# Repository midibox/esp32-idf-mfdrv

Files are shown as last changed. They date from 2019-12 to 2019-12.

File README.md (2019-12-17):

# MBHP_MF_NG for ESP32

## Introduction

This application is originated from the PIC based MBHP_MF_NG project: http://www.ucapps.de/mbhp_mf_ng.html

Currently used as a "Proof of Concept" for ESP32 based motorfader control.

Advantage: due to the dedicated PWM outputs of ESP32 we get much more accurate control over the motors.

More documentation to follow...

## Important

Please optimize the app configuration with "idf.py menuconfig":

* Compiler Options->Optimization Level: set to -Os (Release)
* Component Config->ESP32 Specific: set Minimum Supported ESP32 Revision to 1 (if you have a newer device...)
* Component Config->ESP32 Specific: set CPU frequency to 240 MHz
* Component Config->Log output: set to Warning (or use Info if you want to follow the data flow - but it will decrease performance!)

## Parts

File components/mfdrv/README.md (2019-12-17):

# Motorfader Driver

## Introduction

This driver is originated from:

* the assembly based MBHP_MF_NG project: http://www.ucapps.de/mbhp_mf_ng.html
* C based MIOS32 variant (which is an older implementation): https://github.com/midibox/mios32/blob/master/mios32/common/mios32_mf.c

Currently used as a "Proof of Concept" for ESP32 based motorfader control.

Advantage: due to the dedicated PWM outputs of ESP32 we get much more accurate control over the motors.

More documentation to follow...

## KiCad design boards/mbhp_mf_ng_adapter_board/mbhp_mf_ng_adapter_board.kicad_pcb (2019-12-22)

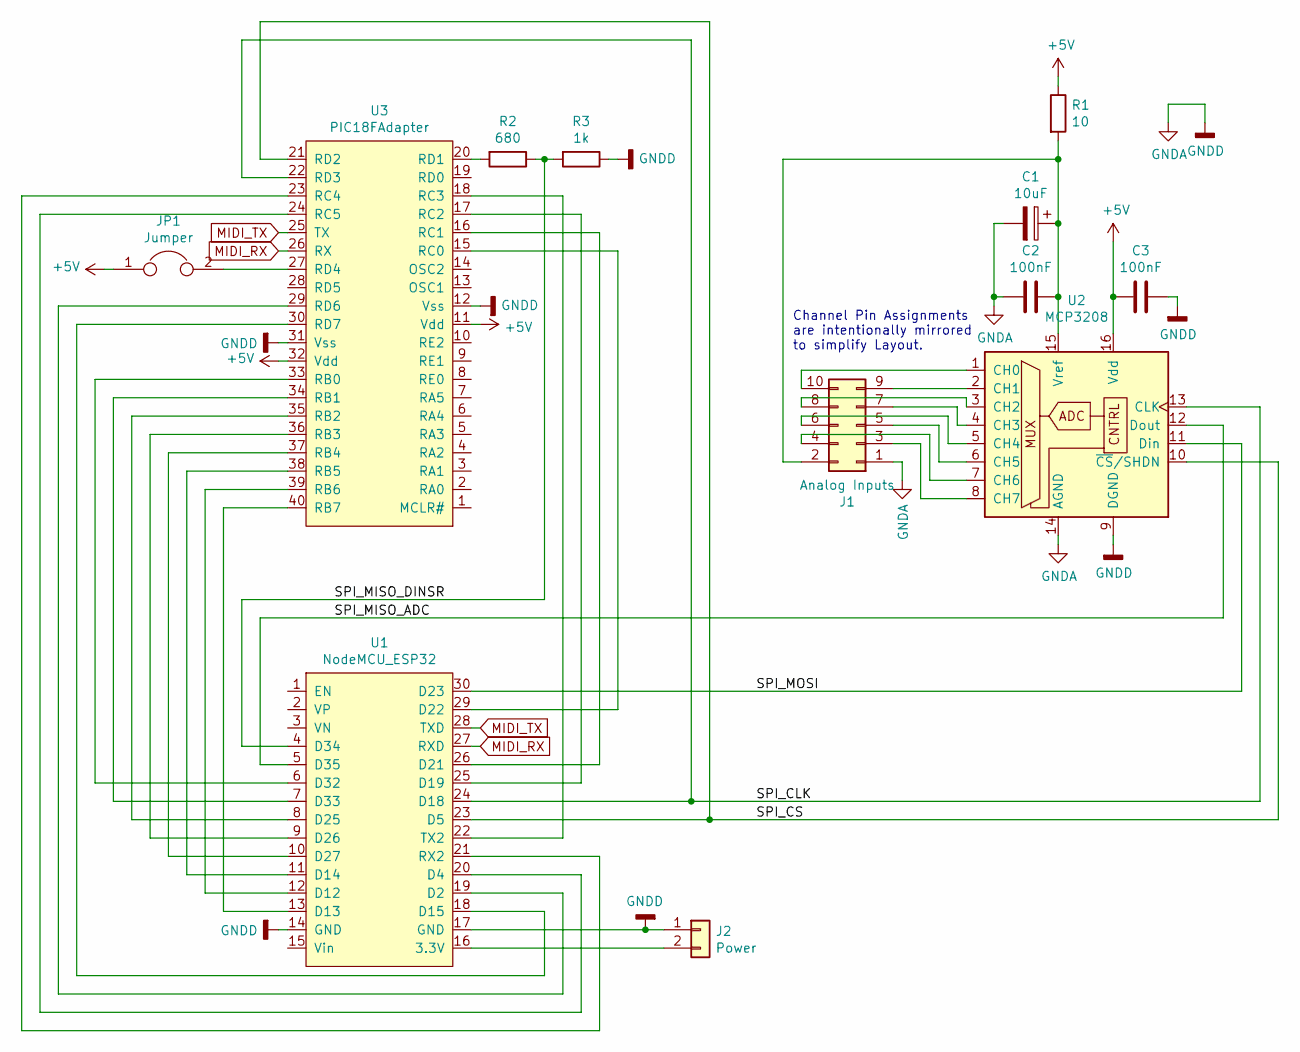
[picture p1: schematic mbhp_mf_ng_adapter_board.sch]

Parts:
C1: 10uF; CP_Radial_D5.0mm_P2.50mm
C2, C3: 100nF; C_Rect_L4.6mm_W2.0mm_P2.50mm_MKS02_FKP02
J1: Analog Inputs; IDC-Header_2x05_P2.54mm_Vertical
J2: Power; PinHeader_1x02_P2.54mm_Vertical
JP1: Jumper; PinHeader_1x02_P2.54mm_Vertical
R1: 10; R_Axial_DIN0207_L6.3mm_D2.5mm_P7.62mm_Horizontal
R2: 680; R_Axial_DIN0207_L6.3mm_D2.5mm_P7.62mm_Horizontal
R3: 1k; R_Axial_DIN0207_L6.3mm_D2.5mm_P7.62mm_Horizontal
U1: NodeMCU_ESP32; NodeMCUESP32
U2: MCP3208; DIP-16_W7.62mm_Socket
U3: PIC18FAdapter; DIP40HookUp

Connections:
+5V: C3.2, JP1.1, R1.1, U2.16 (Vdd), U3.11 (Vdd), U3.32 (Vdd)
/SPI_CLK: U1.24 (D18), U2.13 (CLK), U3.22 (RD3)
/SPI_CS: U1.23 (D5), U2.10 (~CS~/SHDN), U3.21 (RD2)
/SPI_MISO_ADC: U1.5 (D35), U2.12 (Dout)
/SPI_MISO_DINSR: R2.1, R3.2, U1.4 (D34)
/SPI_MOSI: U1.30 (D23), U2.11 (Din)
GNDA: C1.2, C2.2, C3.1, J1.1, J2.1, R3.1, U1.14 (GND), U1.17 (GND), U2.9 (DGND), U2.14 (AGND), U3.12 (Vss), U3.31 (Vss)
MIDI_RX: U1.27 (RXD), U3.26 (RX)
MIDI_TX: U1.28 (TXD), U3.25 (TX)
unnamed: C1.1, C2.1, J1.2, R1.2, U2.15 (Vref)
unnamed: J1.3, U2.8 (CH7)
unnamed: J1.4, U2.7 (CH6)
unnamed: J1.5, U2.6 (CH5)
unnamed: J1.6, U2.5 (CH4)
unnamed: J1.7, U2.4 (CH3)
unnamed: J1.8, U2.3 (CH2)
unnamed: J1.9, U2.2 (CH1)
unnamed: J1.10, U2.1 (CH0)
unnamed: J2.2, U1.16 (3.3V)
unnamed: JP1.2, U3.27 (RD4)
unnamed: R2.2, U3.20 (RD1)
unnamed: U1.6 (D32), U3.33 (RB0)
unnamed: U1.7 (D33), U3.34 (RB1)
unnamed: U1.8 (D25), U3.35 (RB2)
unnamed: U1.9 (D26), U3.36 (RB3)
unnamed: U1.10 (D27), U3.37 (RB4)
unnamed: U1.11 (D14), U3.38 (RB5)
unnamed: U1.12 (D12), U3.39 (RB6)
unnamed: U1.13 (D13), U3.40 (RB7)
unnamed: U1.18 (D15), U3.30 (RD7)
unnamed: U1.19 (D2), U3.29 (RD6)
unnamed: U1.20 (D4), U3.24 (RC5)
unnamed: U1.21 (RX2), U3.23 (RC4)
unnamed: U1.22 (TX2), U3.18 (RC3)
unnamed: U1.25 (D19), U3.17 (RC2)
unnamed: U1.26 (D21), U3.16 (RC1)
unnamed: U1.29 (D22), U3.15 (RC0)

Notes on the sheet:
Channel Pin Assignments are intentionally mirrored to simplify Layout.

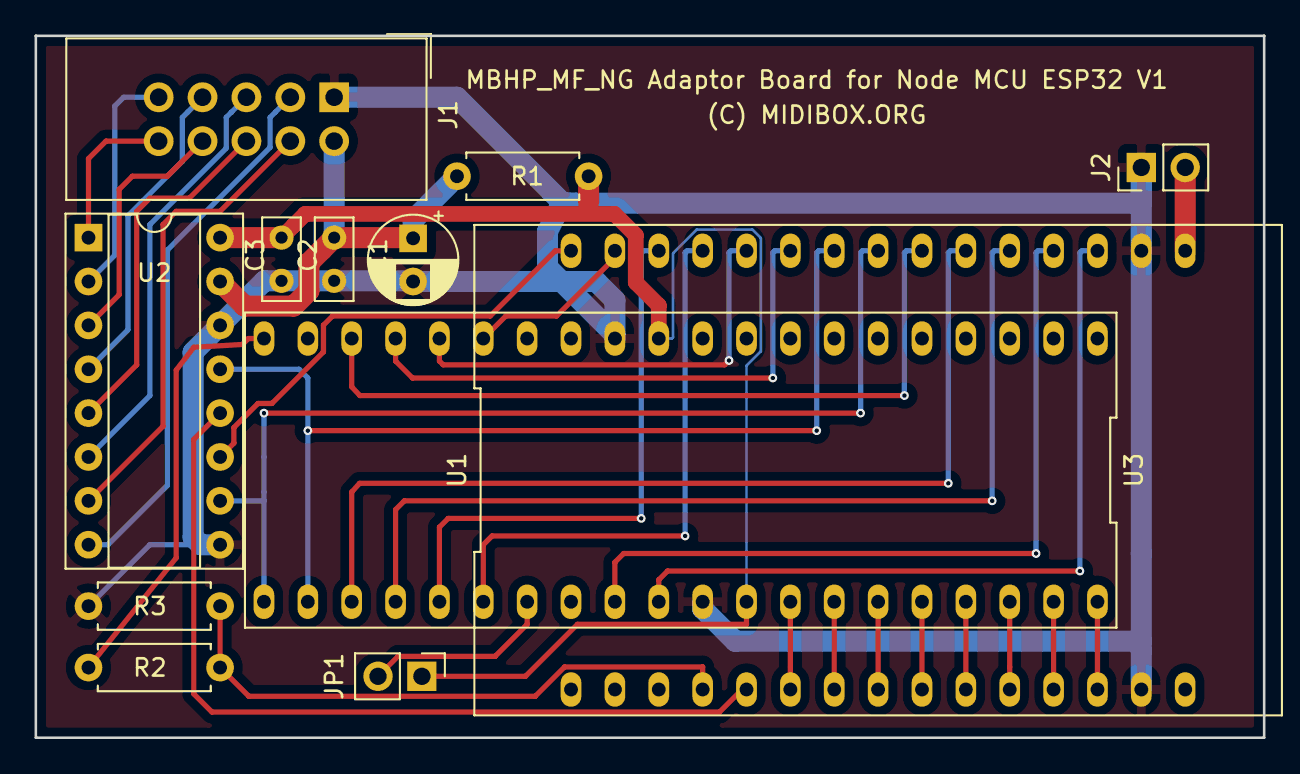
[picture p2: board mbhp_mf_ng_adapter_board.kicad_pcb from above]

Board: 2 copper layers, 71.1 x 40.6 mm, 12 parts (0 on the bottom side), 37 nets.

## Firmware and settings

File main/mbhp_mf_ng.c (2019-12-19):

/*
 * MBHP_MF_NG for ESP32
 *
 * See ../README.md for usage hints
 *
 * =============================================================================
 *
 * MIT License
 *
 * Copyright (c) 2019 Thorsten Klose (tk@midibox.org)
 * 
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
 * =============================================================================
 */

#include <string.h>

#include "freertos/FreeRTOS.h"
#include "freertos/task.h"
#include "freertos/event_groups.h"
#include "esp_system.h"
#include "esp_log.h"
#include "soc/gpio_struct.h"
#include "driver/spi_master.h"
#include "driver/gpio.h"
#include "driver/ledc.h"

#include "blemidi.h"
#include "mfdrv.h"


// IO Pins for SPI connections
#define PIN_NUM_MISO_ADC   35 // instead of standard D19; use this input-only pin for MISO to get D19 for PWM
#define PIN_NUM_MISO_DINSR 34 // input for 74HC165
#define PIN_NUM_MOSI 23
#define PIN_NUM_CLK  18
#define PIN_NUM_CS   5

uint8_t sysex_device_id = 0;

typedef union {
  struct {
    uint8_t ALL[256];
  };
  struct {
    uint8_t name[16];
    uint8_t number_of_faders; // 0x10
    uint8_t operation_mode; // 0x11
    uint8_t merger_mode; // 0x12
    uint8_t pwm_steps; // 0x13
    uint8_t ain_deadband; // 0x14
    uint8_t mf_deadband; // 0x15
    uint8_t touch_sensor_mode; // 0x16
    uint8_t touch_sensor_sensitivity; // 0x17
    uint8_t midi_channel; // 0x18
    uint8_t reserved[7]; // 0x19..0x1f: makes 32 bytes up to here

    uint8_t fader_mode[8];  // 0x20..0x27
    uint8_t min_value_l[8]; // 0x28..0x2f - only low byte is stored
    uint8_t max_value_l[8]; // 0x30..0x37 - only low byte is stored
    uint8_t min_duty_up[8]; // 0x38..0x3f
    uint8_t max_duty_up[8]; // 0x40..0x47
    uint8_t min_duty_down[8]; // 0x48..0x4f
    uint8_t max_duty_down[8]; // 0x50..0x57
    uint8_t reserved2[8];     // 0x58..0x5f
    
    uint8_t reserved_0x6x[16];
    uint8_t reserved_0x7x[16];
    uint8_t reserved_0x8x[16];
    uint8_t reserved_0x9x[16];
    uint8_t reserved_0xax[16];
    uint8_t reserved_0xbx[16];
    uint8_t reserved_0xcx[16];
    uint8_t reserved_0xdx[16];
    uint8_t reserved_0xex[16];
    uint8_t reserved_0xfx[16];
  };
} patch_t;

patch_t patch = { // currently only a single patch is supported
  .name = {0,0,0,0,0,0,0,0,0,0,0,0,0,0,0,0},
  .number_of_faders = MFDRV_NUM,
  .operation_mode = 0,
  .merger_mode = 0,
  .pwm_steps = 64,
  .ain_deadband = 3,
  .mf_deadband = 3,
  .touch_sensor_mode = 1,
  .touch_sensor_sensitivity = 3,
  .midi_channel = 0,
  .fader_mode = {0x01, 0x01, 0x01, 0x01, 0x01, 0x01, 0x01, 0x01},
  .min_value_l = {20, 20, 20, 20, 20, 20, 20, 20},
  .max_value_l = {255, 255, 255, 255, 255, 255, 255, 255},
  .min_duty_up = {10, 10, 10, 10, 10, 10, 10, 10},
  .max_duty_up = {64, 64, 64, 64, 64, 64, 64, 64},
  .min_duty_down = {10, 10, 10, 10, 10, 10, 10, 10},
  .max_duty_down = {64, 64, 64, 64, 64, 64, 64, 64},
};


////////////////////////////////////////////////////////////////////////////////////////////////////
// Sends a SysEx dump with device specific header
////////////////////////////////////////////////////////////////////////////////////////////////////
static int32_t sysex_send_dump(uint8_t *response, size_t response_len, int checksum_start)
{
    size_t packet_len = 2 + 6 + response_len + 2; // includes timestamp, MIDI status and remaining bytes
    if( checksum_start >= 0 )
      packet_len += 1; // + checksum
    
    uint8_t *packet = (uint8_t *)malloc(packet_len * sizeof(uint8_t));
    packet[0] = blemidi_timestamp_high();
    packet[1] = blemidi_timestamp_low();
    packet[2] = 0xf0;
    packet[3] = 0x00;
    packet[4] = 0x00;
    packet[5] = 0x7e;
    packet[6] = 0x4f; // MBHP_MF_NG
    packet[7] = sysex_device_id;
    memcpy(&packet[8], response, response_len);
    packet[packet_len-2] = blemidi_timestamp_high();
    packet[packet_len-1] = 0xf7;

    if( checksum_start >= 0 ) {
      int i;
      uint8_t checksum = 0x00;
      
      for(i=checksum_start; i<response_len-1; ++i) {
	checksum += response[i];
      }
      packet[packet_len-3] = (0x80 - checksum) & 0x7f;
    }
    
    blemidi_send_packet(0, packet, packet_len);

    free(packet);

    return 0; // no error
}

////////////////////////////////////////////////////////////////////////////////////////////////////
// Writes into patch and transfers to application
////////////////////////////////////////////////////////////////////////////////////////////////////
static int32_t sysex_patch_write(uint8_t address, uint8_t value)
{
  patch.ALL[address] = value;

  // transfer to MF driver
  if( address < 0x20 ) { // below MF configuration area
    switch( address ) { // only parameters which have to be forwarded to MF Driver are handled here
    case 0x13: { // PWM Steps
      // TODO
    } break;
      
    case 0x14: { // AIN Deadband
      int mf;
      for(mf=0; mf<MFDRV_NUM; ++mf) {
	mfdrv_config_t cfg = MFDRV_ConfigGet(mf);
	cfg.ain_deadband = value << 2; // 12bit -> 14bit to keep compatibility with MBHP_MF_NG
	MFDRV_ConfigSet(mf, cfg);
      }
    } break;
      
    case 0x15: { // MF Deadband
      int mf;
      for(mf=0; mf<MFDRV_NUM; ++mf) {
	mfdrv_config_t cfg = MFDRV_ConfigGet(mf);
	cfg.mf_deadband = value << 2; // 12bit -> 14bit to keep compatibility with MBHP_MF_NG
	MFDRV_ConfigSet(mf, cfg);
      }
    } break;
    }
  } else { // MF configuration area
    uint32_t mf = address & 0x7;
    switch( address & 0xf8 ) {
      
    case 0x20: { // Fader Mode
      mfdrv_config_t cfg = MFDRV_ConfigGet(mf);
      cfg.fader_mode.ALL = value;
      MFDRV_ConfigSet(mf, cfg);
    } break;
      
    case 0x28: { // Min Value
      mfdrv_config_t cfg = MFDRV_ConfigGet(mf);
      cfg.fader_min_value = (uint16_t)value << 2; // only 8bit... and we convert from 10bit to 12bit to keep compatibility with MBHP_MF_NG
      MFDRV_ConfigSet(mf, cfg);
    } break;
      
    case 0x30: { // Max Value
      mfdrv_config_t cfg = MFDRV_ConfigGet(mf);
      cfg.fader_max_value = (0x1000 - 4*256) + ((uint16_t)value << 2); // only 8bit... and we convert from 10bit to 12bit to keep compatibility with MBHP_MF_NG
      MFDRV_ConfigSet(mf, cfg);
    } break;
      
    case 0x38: { // Min Duty Up
      mfdrv_config_t cfg = MFDRV_ConfigGet(mf);
      cfg.pwm_duty_cycle_up_min = value;
      MFDRV_ConfigSet(mf, cfg);
    } break;
      
    case 0x40: { // Max Duty Up
      mfdrv_config_t cfg = MFDRV_ConfigGet(mf);
      cfg.pwm_duty_cycle_up_max = value;
      MFDRV_ConfigSet(mf, cfg);
    } break;
      
    case 0x48: { // Min Duty Down
      mfdrv_config_t cfg = MFDRV_ConfigGet(mf);
      cfg.pwm_duty_cycle_down_min = value;
      MFDRV_ConfigSet(mf, cfg);
    } break;
      
    case 0x50: { // Max Duty Down
      mfdrv_config_t cfg = MFDRV_ConfigGet(mf);
      cfg.pwm_duty_cycle_down_max = value;
      MFDRV_ConfigSet(mf, cfg);
    } break;
      
    }
  }
  
  return 0; // no error
}

////////////////////////////////////////////////////////////////////////////////////////////////////
// This callback is called whenever a new MIDI message is received
////////////////////////////////////////////////////////////////////////////////////////////////////
static void callback_midi_message_received(uint8_t blemidi_port, uint16_t timestamp, uint8_t midi_status, uint8_t *remaining_message, size_t len, size_t continued_sysex_pos)
{
  static uint8_t expect_continued_sysex = 0;
  
  ESP_LOGI(BLEMIDI_TAG, "CALLBACK blemidi_port=%d, timestamp=%d, midi_status=0x%02x, len=%d, continued_sysex_pos=%d, remaining_message:", blemidi_port, timestamp, midi_status, len, continued_sysex_pos);
  esp_log_buffer_hex(BLEMIDI_TAG, remaining_message, len);

  // SysEx communication
  uint8_t *sysex_stream = remaining_message;
  if( midi_status == 0xf0 &&
      (continued_sysex_pos ||
       (len >= 6 &&
	*(sysex_stream++) == 0x00 &&
	*(sysex_stream++) == 0x00 &&
	*(sysex_stream++) == 0x7e &&
	*(sysex_stream++) == 0x4f && // MBHP_MF_NG
	*(sysex_stream++) == sysex_device_id))
      ) {

    if( continued_sysex_pos && !expect_continued_sysex ) {
      return; // seems that this was continued sysex data for something else...
    }
    expect_continued_sysex = 0; // has to be set explicitely again if required
    
    uint8_t cmd = continued_sysex_pos ? 0x2 : *(sysex_stream++);
    switch( cmd ) {
    case 0x1: { // Patch Read
      int i;
      uint8_t patch_number = *(sysex_stream++); // TODO: handle patch number

      const size_t response_len = 1+1+512;
      uint8_t response[response_len];
      uint8_t *response_ptr = response;
	
      *(response_ptr++) = 0x02; // Patch Write
      *(response_ptr++) = patch_number;

      for(i=0; i<sizeof(patch_t); ++i) {
	*(response_ptr++) = patch.ALL[i] & 0xf;
	*(response_ptr++) = patch.ALL[i] >> 4;
      }

      sysex_send_dump(response, response_len, 2);
    } break;
	
    case 0x2: { // Patch Write
      // this is the only command which could be continued over multiple packets!
      static uint8_t patch_number = 0;
      static uint8_t checksum = 0x00;

      int start_pos;
      if( !continued_sysex_pos ) {
	patch_number = *(sysex_stream++); // TODO: handle patch number
	checksum = 0;
	start_pos = 0;
      } else {
	start_pos = continued_sysex_pos - 7;
      }
      
      uint8_t *checksum_scan_ptr = sysex_stream;
      int i;
      for(i=start_pos; i<2*sizeof(patch_t); ++i) {
	// transfer value to patch structure
	if( (i % 2) == 0 ) {
	  patch.ALL[i/2] &= 0xf0;
	  patch.ALL[i/2] |= *checksum_scan_ptr & 0x0f;
	} else {
	  patch.ALL[i/2] &= 0x0f;
	  patch.ALL[i/2] |= (*checksum_scan_ptr & 0x0f) << 4;
	}
	
	checksum += *(checksum_scan_ptr++);

	if( checksum_scan_ptr == (remaining_message+len) ) {
	  expect_continued_sysex = 1;
	  return; // expecting additional packets
	}
      }
      uint8_t expected_checksum = (0x80 - checksum) & 0x7f;

      if( expected_checksum == *checksum_scan_ptr ) {
	// if checksum matching: transfer patch structure to MFDRV
	int i;
	for(i=0; i<sizeof(patch_t); ++i) {
	  sysex_patch_write(i, patch.ALL[i]);
	}
      }
      
      uint8_t response[2] = {(expected_checksum == *checksum_scan_ptr) ? 0xf : 0xe, expected_checksum};
      sysex_send_dump(response, 2, -1); // Ack or Error Response
    } break;
	
    case 0x6: { // Parameter Write
      uint32_t address = (*(sysex_stream++) & 0x01) << 7;
      address |= (*(sysex_stream++) & 0x7f);

      int num_bytes = (len-7) / 2;
      int i;
      for(i=0; i<num_bytes; ++i, ++address) {
	uint8_t data = (*(sysex_stream++) & 0x0f);
	data |= (*(sysex_stream++) & 0x0f) << 4;
	//printf("%d: 0x%02x = 0x%02x\n", i, address, data);

	if( address < sizeof(patch_t) ) {
	  sysex_patch_write(address, data);
	}
      }

      {
	uint8_t response[2] = {0xf, 0x00};
	sysex_send_dump(response, 2, -1); // Ack
      }
    } break;
	
    case 0x9: { // Faders Get
      uint8_t first_fader = *(sysex_stream++);

      {
	uint8_t response[2+16];
	uint8_t *response_ptr = response;
	*(response_ptr++) = 0x0a; // like "Faders Set"
	*(response_ptr++) = first_fader;

	int i;
	for(i=first_fader; i<8; ++i) {
	  uint16_t pos = MFDRV_FaderPositionGet(i);
	  *(response_ptr++) = pos & 0x7f;
	  *(response_ptr++) = pos >> 7;
	}
	  
	sysex_send_dump(response, 2+2*(8-first_fader), -1); // Ack
      }
    } break;
	
    case 0xa: { // Faders Set
      uint8_t first_fader = *(sysex_stream++);

      int i;
      int num_faders = (len-7) / 2;
      for(i=0; i<num_faders; ++i) {
	uint16_t pos = *(sysex_stream++);
	pos |= ((uint16_t)*(sysex_stream++)) << 7;

	uint8_t mf = i + first_fader;
	MFDRV_TouchDetectionReset(mf);
	MFDRV_FaderMove(mf, pos << 2); // convert to MBHP_MF_NG resolution
      }

      {
	uint8_t response[2] = {0xf, 0x00};
	sysex_send_dump(response, 2, -1); // Ack
      }
    } break;
	
    case 0xb: { // Trace Request
      uint8_t mf = *(sysex_stream++);
      uint8_t scale = *(sysex_stream++);
      MFDRV_TraceRequest(mf, scale);
    } break;
	
    case 0xf: { // Ping
      // feedback detection: only send back if no additional byte has been received!
      if( len == 6 ) {
	uint8_t response[2] = {0xf, 0x00};
	sysex_send_dump(response, 2, -1); // Pong
      }
    } break;
    default: { // Invalid Command
      uint8_t response[2] = {0xe, 0x00};
      sysex_send_dump(response, 2, -1); // invalid command
    }
    }
  }
    

  // now handle different fader modes
  // TOOD: ... currently only pitch bend supported!
  if( (midi_status & 0xf0) == 0xe0 ) {
    uint32_t mf = midi_status & 0xf;
    uint16_t value = remaining_message[0] | ((uint16_t)remaining_message[1] << 7);

    if( mf < MFDRV_NUM ) {
      MFDRV_FaderMove(mf, (uint16_t)value >> 2); // 14bit -> 12bit
    }
  }
}


////////////////////////////////////////////////////////////////////////////////////////////////////
// Called whenever a motorfader is moved manually
////////////////////////////////////////////////////////////////////////////////////////////////////
static void callback_manual_fader_change(uint32_t mf, uint16_t value)
{
  // send PitchBend event
  // TODO: consider patch.operation_mode
  // TODO: more comfortable packet creation via special APIs

  uint8_t send = 1;
  if( patch.touch_sensor_mode >= 3 && MFDRV_TouchSensorGet(mf) != 0 ) { // only send if touch sensor active
    send = 0; // sensor not touched (value != 0) -> don't send
  }

  if( send ) {
    // 12bit -> 14bit value
    value <<= 2;

    uint8_t packet[5] = {blemidi_timestamp_high(), blemidi_timestamp_low(), 0xe0 + mf, value & 0x7f, value >> 7 };
    blemidi_send_packet(0, packet, 5);
  }
}


////////////////////////////////////////////////////////////////////////////////////////////////////
// Called whenever a touch sensor is activated.
// Note: the value is typically low-active, means: if 0, sensor is touched)
////////////////////////////////////////////////////////////////////////////////////////////////////
static void callback_touch_sensor_change(uint32_t ts, uint8_t value)
{
  //printf("Touch Sensor #%d %s\n", ts+1, value ? "untouched" : "touched");

  if( patch.touch_sensor_mode >= 1 ) { // touch sensor will generate a MIDI event
    // TODO: make MIDI event optional depending on patch.operation_mode    
    uint8_t packet[5] = {blemidi_timestamp_high(), blemidi_timestamp_low(), 0x90, 0x68 + ts, value ? 0x00 : 0x7f };
    blemidi_send_packet(0, packet, 5);
  }

  if( patch.touch_sensor_mode >= 2 ) { // touch sensor will suspend motor
    MFDRV_SuspendSet(ts, value ? 0 : 1);
  }
  
}


////////////////////////////////////////////////////////////////////////////////////////////////////
// This task is periodically called to convert fader values + touch sensors, and control the motors
////////////////////////////////////////////////////////////////////////////////////////////////////
static void task_mf(void *pvParameters)
{
  spi_device_handle_t spi_adc;
  esp_err_t ret;

  //////////////////////////////////////////////////////////////////////////////////////////////////
  // SPI Initialization
  //////////////////////////////////////////////////////////////////////////////////////////////////

  // we need two separate busses for the same SPI
  // because ADC and DIN SR are connected to different MISO pins
  spi_bus_config_t buscfg_adc = {
        .miso_io_num=PIN_NUM_MISO_ADC,
        .mosi_io_num=PIN_NUM_MOSI,
        .sclk_io_num=PIN_NUM_CLK,
        .quadwp_io_num=-1,
        .quadhd_io_num=-1,
        .max_transfer_sz=8
  };

  spi_bus_config_t buscfg_dinsr = {
        .miso_io_num=PIN_NUM_MISO_DINSR,
        .mosi_io_num=PIN_NUM_MOSI,
        .sclk_io_num=PIN_NUM_CLK,
        .quadwp_io_num=-1,
        .quadhd_io_num=-1,
        .max_transfer_sz=1
  };

  // the device config
  // note: originally I wanted to define a separate one for dinsr, but unfortunately the driver doesn't allow to switch the CS polarity during runtime
  // as a workaround we switch the polarity in the HW registers directory whenever required
  spi_device_interface_config_t devcfg_adc = {
        .command_bits=0,
        .address_bits=0,
        .dummy_bits=0,
        .clock_speed_hz=1*1000*1000,           //Clock out at 1 MHz
        .duty_cycle_pos=128,
        .mode=0,
        .spics_io_num=PIN_NUM_CS,
        .queue_size=8
    };

#if 0  
  spi_device_interface_config_t devcfg_dinsr = {
        .command_bits=0,
        .address_bits=0,
        .dummy_bits=0,
        .clock_speed_hz=1*1000*1000,           //Clock out at 1 MHz
        .duty_cycle_pos=128,
        .mode=0,
	.flags = SPI_DEVICE_POSITIVE_CS,
        .spics_io_num=PIN_NUM_CS,
        .queue_size=1
    };
#endif
  
  // Initialize the SPI bus for ADC
  ret=spi_bus_initialize(VSPI_HOST, &buscfg_adc, 0);
  ESP_ERROR_CHECK(ret);

  // Attach the ADC to the SPI bus
  ret=spi_bus_add_device(VSPI_HOST, &devcfg_adc, &spi_adc);
  ESP_ERROR_CHECK(ret);

  // prepare ADC transactions 
  uint8_t adc_send_buffer[8][3];
  uint8_t adc_receive_buffer[8][3];
  spi_transaction_t spi_transaction_adc[8];
  {
    memset(&spi_transaction_adc, 0, sizeof(spi_transaction_adc));

    int i;
    for(i=0; i<8; ++i) {
      // retrieve conversion values
      // shift in start bit + SGL + MSB of channel selection, shift out dummy byte
      adc_send_buffer[i][0] = 0x6 | (i >> 2);
      // shift in remaining 2 bits of channel selection, shift out MSBs of conversion value
      adc_send_buffer[i][1] = i << 6;
      // shift in dummy, shift out LSBs of conversion value
      adc_send_buffer[i][2] = 0x00;

      spi_transaction_adc[i].length = 3*8;
      spi_transaction_adc[i].tx_buffer = adc_send_buffer[i];
      spi_transaction_adc[i].rx_buffer = adc_receive_buffer[i];
    }
  }


  // prepare DINSR transactions 
  uint8_t dinsr_receive_buffer[1];
  spi_transaction_t spi_transaction_dinsr[1];
  {
    memset(&spi_transaction_dinsr, 0, sizeof(spi_transaction_dinsr));

    spi_transaction_dinsr[0].length = 1*8;
    spi_transaction_dinsr[0].tx_buffer = NULL;
    spi_transaction_dinsr[0].rx_buffer = &dinsr_receive_buffer[0];
  }


  
  //////////////////////////////////////////////////////////////////////////////////////////////////
  // initialize Motorfader Driver
  //////////////////////////////////////////////////////////////////////////////////////////////////

  // the driver itself
  MFDRV_Init();

  // then restore configuration values from patch structure
  {
    int i;
    for(i=0; i<sizeof(patch_t); ++i) {
      sysex_patch_write(i, patch.ALL[i]);
    }
  }


  //////////////////////////////////////////////////////////////////////////////////////////////////
  // Finally: the endless running control loop
  //////////////////////////////////////////////////////////////////////////////////////////////////
  while( 1 ) {
    int i;

    ////////////////////////////////////////////////////////////////////////////////////////////////
    // increase BLE MIDI Timestamp
    ////////////////////////////////////////////////////////////////////////////////////////////////
    blemidi_tick_ms(1);

    
    ////////////////////////////////////////////////////////////////////////////////////////////////
    // ADC Conversions
    ////////////////////////////////////////////////////////////////////////////////////////////////
    for(i=0; i<8; ++i) {
      ret = spi_device_queue_trans(spi_adc, &spi_transaction_adc[i], portMAX_DELAY);
      assert(ret==ESP_OK);
    }

    // keep SPI transfer running, get back in 1 mS when results should be available
    vTaskDelay( 1 * portTICK_PERIOD_MS );

    // get results from receive buffers
    uint16_t adc_results[8];
    for(i=0; i<8; ++i) {
      spi_transaction_t *ret_trans;
      ret = spi_device_get_trans_result(spi_adc, &ret_trans, portMAX_DELAY);
      assert(ret==ESP_OK);
      assert(ret_trans == &spi_transaction_adc[i]);
	
      adc_results[i] = ((adc_receive_buffer[i][1] & 0xf) << 8) | (adc_receive_buffer[i][2]);
    }
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
void app_main()
{
  // install BLE MIDI service
  int status = blemidi_init(callback_midi_message_received);
  if( status < 0 ) {
    ESP_LOGE(BLEMIDI_TAG, "BLE MIDI Driver returned status=%d", status);
  } else {
    ESP_LOGI(BLEMIDI_TAG, "BLE MIDI Driver initialized successfully");
    xTaskCreate(task_mf, "task_mf", 4096, NULL, 8, NULL);    
  }
}

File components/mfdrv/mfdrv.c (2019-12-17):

/* \defgroup MFDRV
 *
 * Motorfader Driver
 *
 * See README.md for usage hints
 *
 * =============================================================================
 *
 * MIT License
 *
 * Copyright (c) 2019 Thorsten Klose (tk@midibox.org)
 * 
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
 * =============================================================================
 */

/////////////////////////////////////////////////////////////////////////////
// Include files
/////////////////////////////////////////////////////////////////////////////

#include <stdlib.h>

#include "esp_system.h"
#include "soc/gpio_struct.h"
#include "driver/gpio.h"
#include "driver/ledc.h"


#include "mfdrv.h"

/////////////////////////////////////////////////////////////////////////////
// Local defines/macros
/////////////////////////////////////////////////////////////////////////////

#define REPEAT_CTR_RELOAD         31  // retries to reach target position
#define TIMEOUT_CTR_RELOAD       255 // give up after how many mS
#define MANUAL_MOVE_CTR_RELOAD   255 // ignore new position request for how many mS
#define SLOWDOWN_THRESHOLD       512


#define MFDRV_PWM_CH_NUM         (2*MFDRV_NUM)


const ledc_channel_config_t ledc_channel[MFDRV_PWM_CH_NUM] = {
  { .timer_sel = LEDC_TIMER_0, .channel = LEDC_CHANNEL_0, .gpio_num = 13, .speed_mode = LEDC_HIGH_SPEED_MODE }, // MF1 Up
  { .timer_sel = LEDC_TIMER_1, .channel = LEDC_CHANNEL_0, .gpio_num = 12, .speed_mode = LEDC_LOW_SPEED_MODE  }, // MF1 Down
  { .timer_sel = LEDC_TIMER_0, .channel = LEDC_CHANNEL_1, .gpio_num = 14, .speed_mode = LEDC_HIGH_SPEED_MODE }, // MF2 Up
  { .timer_sel = LEDC_TIMER_1, .channel = LEDC_CHANNEL_1, .gpio_num = 27, .speed_mode = LEDC_LOW_SPEED_MODE  }, // MF2 Down
  { .timer_sel = LEDC_TIMER_0, .channel = LEDC_CHANNEL_2, .gpio_num = 26, .speed_mode = LEDC_HIGH_SPEED_MODE }, // MF3 Up
  { .timer_sel = LEDC_TIMER_1, .channel = LEDC_CHANNEL_2, .gpio_num = 25, .speed_mode = LEDC_LOW_SPEED_MODE  }, // MF3 Down
  { .timer_sel = LEDC_TIMER_0, .channel = LEDC_CHANNEL_3, .gpio_num = 33, .speed_mode = LEDC_HIGH_SPEED_MODE }, // MF4 Up
  { .timer_sel = LEDC_TIMER_1, .channel = LEDC_CHANNEL_3, .gpio_num = 32, .speed_mode = LEDC_LOW_SPEED_MODE  }, // MF4 Down
  { .timer_sel = LEDC_TIMER_0, .channel = LEDC_CHANNEL_4, .gpio_num = 15, .speed_mode = LEDC_HIGH_SPEED_MODE }, // MF5 Up
  { .timer_sel = LEDC_TIMER_1, .channel = LEDC_CHANNEL_4, .gpio_num =  2, .speed_mode = LEDC_LOW_SPEED_MODE  }, // MF5 Down
  { .timer_sel = LEDC_TIMER_0, .channel = LEDC_CHANNEL_5, .gpio_num =  4, .speed_mode = LEDC_HIGH_SPEED_MODE }, // MF6 Up
  { .timer_sel = LEDC_TIMER_1, .channel = LEDC_CHANNEL_5, .gpio_num = 16, .speed_mode = LEDC_LOW_SPEED_MODE  }, // MF6 Down
  { .timer_sel = LEDC_TIMER_0, .channel = LEDC_CHANNEL_6, .gpio_num = 17, .speed_mode = LEDC_HIGH_SPEED_MODE }, // MF7 Up
  { .timer_sel = LEDC_TIMER_1, .channel = LEDC_CHANNEL_6, .gpio_num = 19, .speed_mode = LEDC_LOW_SPEED_MODE  }, // MF7 Down
  { .timer_sel = LEDC_TIMER_0, .channel = LEDC_CHANNEL_7, .gpio_num = 21, .speed_mode = LEDC_HIGH_SPEED_MODE }, // MF8 Up
  { .timer_sel = LEDC_TIMER_1, .channel = LEDC_CHANNEL_7, .gpio_num = 22, .speed_mode = LEDC_LOW_SPEED_MODE  }, // MF8 Down
};


/////////////////////////////////////////////////////////////////////////////
// Local types
/////////////////////////////////////////////////////////////////////////////

typedef union {
  struct {
    uint32_t ALL0:32;
    uint32_t ALL1:32;
    uint32_t ALL2:32;
  };
  struct {
#if 0  // bitfields don't work with ESP32 - values will be overwritten ?!?
    uint32_t up:1;
    uint32_t down:1;
    uint32_t suspended:1;
    uint32_t idle:1;
    uint32_t direct_control:1;
    uint32_t dummy:3+8; // fill to 16bit
#else
    uint8_t up;
    uint8_t down;
    uint8_t suspended;
    uint8_t idle;
    uint8_t direct_control;
#endif
    
    uint16_t target_pos;
    uint16_t current_pos;
    uint8_t  current_ts_value;

    uint8_t  duty_cycle;
    uint8_t  manual_move_ctr;
    uint8_t  timeout_ctr;
    uint8_t  repeat_ctr;

    mfdrv_config_t config;
  };
  struct {
    mfdrv_direction_t direction;
  };
} mf_state_t;

typedef enum {
  MF_TRACE_STATE_IDLE = 0,
  MF_TRACE_STATE_ARMED,
  MF_TRACE_STATE_RUNNING,
  MF_TRACE_STATE_FINISHED,
  MF_TRACE_STATE_SENT
} mf_trace_state_t;

typedef struct {
  mf_trace_state_t state;
  uint8_t fader;
  uint8_t scale;
  uint8_t scale_ctr;
  uint16_t pos;
  uint16_t data[256];
} mf_trace_t;


/////////////////////////////////////////////////////////////////////////////
// Local variables
/////////////////////////////////////////////////////////////////////////////

#if MFDRV_NUM

// control variables for motorfaders
static mf_state_t mf_state[MFDRV_NUM];
static mf_trace_t mf_trace;
#endif


/////////////////////////////////////////////////////////////////////////////
// Prototypes
/////////////////////////////////////////////////////////////////////////////


/////////////////////////////////////////////////////////////////////////////
//! Initializes motorfader driver
//! \return < 0 if initialisation failed
/////////////////////////////////////////////////////////////////////////////
int32_t MFDRV_Init(void)
{
#if !MFDRV_NUM
  return -1; // no motorfaders
#else

  int i;
  for(i=0; i<MFDRV_NUM; ++i) {
    mf_state[i].ALL0 = 0;
    mf_state[i].ALL1 = 0;
    mf_state[i].ALL2 = 0;

    mf_state[i].config.fader_mode.ALL = 0;
    mf_state[i].config.fader_mode.enabled = 1;
    mf_state[i].config.ain_deadband = 15;
    mf_state[i].config.mf_deadband = 15;
    mf_state[i].config.fader_min_value = 80;
    mf_state[i].config.fader_max_value = 4000;
    mf_state[i].config.pwm_period = 64;
    mf_state[i].config.pwm_duty_cycle_down_max = 64;
    mf_state[i].config.pwm_duty_cycle_down_min = 32;
    mf_state[i].config.pwm_duty_cycle_up_max = 64;
    mf_state[i].config.pwm_duty_cycle_up_min = 32;
  }

  mf_trace.state = MF_TRACE_STATE_IDLE;

  // PWM via LEDC driver
  ledc_timer_config_t ledc_timer = {
    .duty_resolution = LEDC_TIMER_6_BIT,   // resolution of PWM duty
    .freq_hz = 200000,                     // frequency of PWM signal (currently hardcoded)
    .speed_mode = LEDC_HIGH_SPEED_MODE,    // timer mode
    .timer_num = LEDC_TIMER_0              // timer index
  };
  
  // Set configuration of timer0 for high speed channels
  ledc_timer_config(&ledc_timer);

  // Prepare and set configuration of timer1 for low speed channels
  ledc_timer.speed_mode = LEDC_LOW_SPEED_MODE;
  ledc_timer.timer_num = LEDC_TIMER_1;
  ledc_timer_config(&ledc_timer);

  // Set LED Controller with previously prepared configuration
  {
    int ch;
    for (ch = 0; ch < MFDRV_PWM_CH_NUM; ch++) {
      ledc_channel_config(&ledc_channel[ch]);
    }
  }

  // Initialize fade service. (none used...)
  ledc_fade_func_install(0);

  return 0;
#endif
}
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

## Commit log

2019-12-21 initial version of MBHP_MF_NG adaptor board
    [mbhp_mf_ng_adapter_board.kicad_pcb, mbhp_mf_ng_adapter_board.sch]
2019-12-22 Adaptor prototype ready for OSHpark
    [mbhp_mf_ng_adapter_board.kicad_pcb, mbhp_mf_ng_adapter_board.sch]
2020-01-02 blemidi driver updates
